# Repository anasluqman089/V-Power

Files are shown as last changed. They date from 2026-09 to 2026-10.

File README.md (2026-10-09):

# V-Power Handheld Console

V-Power handheld console

V-Power is a compact handheld console built around the Seeed Studio XIAO ESP32-S3 Sense. It brings together an OLED display, physical controls, a camera, SD-card storage, and battery monitoring in a custom PCB and 3D-printed case.

## Features

- Seeed Studio XIAO ESP32-S3 Sense
- 0.96-inch OLED display
- Four directional buttons and a rotary encoder
- Camera and photo gallery
- microSD card support
- MAX17043 battery fuel gauge
- Power indicator and low-battery LEDs
- Built-in Snake, Dodge, and Pong games in the `mini_handheld_console` project

## Bill of Materials

Prices are estimates and may change. The linked products are examples of the parts used for this build.

| Item | Component | Price (USD) | Qty | Example source |
| :--: | :--- | ---: | :--: | :--- |
| 1 | XIAO ESP32-S3 Sense | $13.90 | 1 | [Seeed Studio](https://www.seeedstudio.com/XIAO-ESP32S3-Sense-p-5639.html) |
| 2 | 0.96-inch OLED display | $6.99 | 1 | [Amazon](https://www.amazon.com/Dorhea-Display-3-3V-5V-Arduino-Raspberry/dp/B07FK8GB8T/ref=sr_1_5) |
| 3 | MAX17043 battery fuel gauge | $9.49 | 1 | [Amazon](https://www.amazon.com/HiLetgo-MAX17043-Lithium-Battery-Converter/dp/B01NBE99EP/ref=sr_1_3) |
| 4 | Rotary encoder | $6.99 | 1 | [Amazon](https://www.amazon.com/AIMPGSTL-Rotary-Encoder-Arduino-Raspberry/dp/B0FHDG9BKF/ref=sr_1_6) |
| 5 | Tactile push buttons | $4.99 | 4 | [Amazon](https://www.amazon.com/DAOKI-Miniature-Momentary-Tactile-Quality/dp/B01CGMP9GY/ref=sr_1_8) |
| 6 | LEDs | $6.99 | 2 | [Amazon](https://www.amazon.com/CHANZON-Assortment-Colors-Clear-Transparent/dp/B01AUI4VSI/ref=sr_1_6) |
| 7 | 40 x 30 x 8 mm Li-ion/LiPo battery | $2.20 | 1 | [Shopee](https://shopee.com.my/Original-Rechargeable-Battery-3.7V-150mAh-300mAh-600mAh-800mAh-1000mAh-1200mAh-1500mAh-3000mAh-5000mAh-bateri-china-cina-i.237274675.3651954444) |
| 8 | 3D printing | $5.00 | 1 | - |
| 9 | PCB | $4.00 | 1 | - |

## Controls

**Menu:** Turn the encoder to choose a game. Press **RIGHT** to launch it or **LEFT** to open the camera.

**Camera:** Press **RIGHT** to take a photo, **UP** to open the gallery, or **LEFT** to return to the menu.

**Gallery:** Turn the encoder to browse photos. Press **LEFT** to return to the camera.

**Games:** Use the directional buttons and encoder for game controls. Hold **LEFT** for five seconds to return to the menu.

The game-exit delay is set by `GAME_EXIT_TIME` in [the firmware pin definitions](Firmware/V-Power/mini_handheld_console/include/pins.h).

## Hardware Pinout

| Function | XIAO pin |
| :--- | :---: |
| UP button | D1 |
| Power LED | D2 |
| Low-battery LED | D3 |
| OLED and MAX17043 SDA | D4 |
| OLED and MAX17043 SCL | D5 |
| Rotary encoder A | D6 |
| Rotary encoder B | D7 |
| DOWN button | D8 |
| LEFT button | D9 |
| RIGHT button | D10 |

## Games and SD Card

The `mini_handheld_console` firmware includes Snake, Dodge, and Pong, which run without an SD card. The firmware also scans `/games` for files ending in `.GAM`, but external game files are not currently parsed or executed; selecting one displays a placeholder screen.

Photos taken with the camera are saved to `/photos`. The card is organized like this:

```text
games/
  game1.GAM
  game2.GAM
photos/
  PHOTO001.JPG
  PHOTO002.JPG
```

The gallery reads JPEG images from `/photos` and displays them on the OLED.

## Battery LEDs

The MAX17043 reports battery charge over I²C. The power LED stays on while the console is running. The warning LED blinks when the reported charge is at or below 15%; this threshold is defined by `LOW_BATTERY_PERCENT` in [the firmware pin definitions](Firmware/V-Power/mini_handheld_console/include/pins.h).

## Hardware Note

The current pinout assigns D8, D9, and D10 to buttons. On the XIAO ESP32-S3 Sense, these pins are also used by the onboard microSD interface. As a result, the buttons and onboard SD card cannot reliably operate together with this wiring. Change the wiring and pin assignments, or use a different SD connection, before relying on both at once.

## Build and Assembly

1. Assemble the circuit using the PCB or jumper wires. Follow the pinout above and check the SD-card pin conflict before soldering.
2. Install the [PlatformIO IDE extension for VS Code](https://docs.platformio.org/en/latest/integration/ide/vscode.html).
3. Open `Firmware/V-Power/mini_handheld_console` in VS Code and build the project with PlatformIO.
4. Connect the XIAO ESP32-S3 Sense and upload the firmware.
5. Print the case from the CAD files, or make a case of your own.

*Finished*

## Schematic



## PCB





## CAD





### Body 





### LID



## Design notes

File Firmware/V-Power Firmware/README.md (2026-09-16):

# Mini Handheld Console

## Project

PlatformIO project for XIAO ESP32-S3 Sense with 128x64 OLED, four buttons, rotary encoder, two LEDs, MAX17043, camera and onboard microSD.

## Controls

Menu: encoder moves, RIGHT launches, LEFT enters camera.
Camera: RIGHT takes photo, UP opens gallery, LEFT returns to menu.
Gallery: encoder browses, LEFT returns to camera.
Game: LEFT held for 5 seconds returns to menu.
LED1: on when powered.
LED2: blinks below the configured battery threshold.

## SD layout

/sd/games/*.GAM
/sd/photos/*.JPG

## Important hardware note

The XIAO ESP32-S3 Sense onboard microSD uses GPIO21 for CS and D8/D9/D10 for SPI. The requested SW2=D8, SW3=D9 and SW4=D10 therefore conflict with the onboard microSD interface. The firmware can compile with the requested pin map, but the SD card and those three buttons cannot reliably operate at the same time on the stock Sense SD connection. Move those button signals to unused GPIOs or use a different SD connection before expecting the SD features to work.

## Build

Open the folder in VS Code with PlatformIO and build/upload the project.

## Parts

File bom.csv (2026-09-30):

Item | Component | Price ($) | Qty | Buy Link
1 | XIAO ESP32-S3 Sense | $13.90 | 1 | https://www.seeedstudio.com/XIAO-ESP32S3-Sense-p-5639.html
2 | 0.96 Inch OLED Display | $6.99 | 1 | https://www.shopee.com.my/search?keyword=0.96%20OLED%20SSD1306%20128x64%20I2C
3 | MAX17043 | $9.49 | 1 | https://www.amazon.com/HiLetgo-MAX17043-Lithium-Battery-Converter/dp/B01NBE99EP/ref=sr_1_3
4 | Rotary Encoder | $6.99 | 1 | https://www.amazon.com/AIMPGSTL-Rotary-Encoder-Arduino-Raspberry/dp/B0FHDG9BKF/ref=sr_1_6
5 | Tactile Push Button | $4.99 | 4 | https://www.amazon.com/DAOKI-Miniature-Momentary-Tactile-Quality/dp/B01CGMP9GY/ref=sr_1_8
6 | LED | $6.99 | 2 | https://www.amazon.com/CHANZON-Assortment-Colors-Clear-Transparent/dp/B01AUI4VSI/ref=sr_1_6
7 | 40x30x8mm Li-ion/LiPo Battery | $2.20 | 1 | https://shopee.com.my/Original-Rechargeable-Battery-3.7V-150mAh-300mAh-600mAh-800mAh-1000mAh-1200mAh-1500mAh-3000mAh-5000mAh-bateri-china-cina-i.237274675.365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
8 | 3d printing | ~$5 | 1 | -
8 | PCB | $4.40 | 1 | -

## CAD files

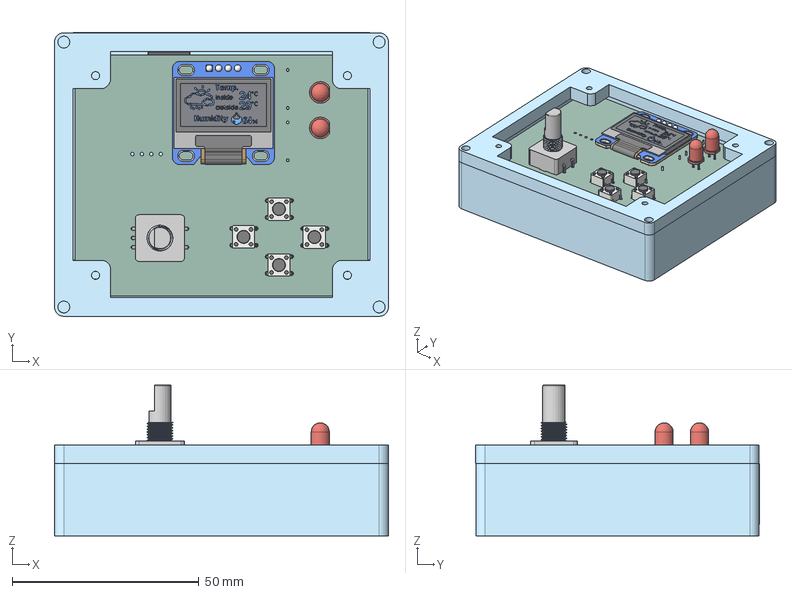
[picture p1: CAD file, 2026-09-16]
CAD/V-Power_CAD.step
89.5 x 76.0 x 40.4 mm
DF40HC(3.0)-30DS:1__Körper3
Seeed Studio XIAO-ESP32-S3 (Sense):1__PCB (1) x 16
LED_D5.0mm_1
V-Power_silkscreen x 6
DF40HC(3.0)-30DS:1__Körper14
JUSHUO AFC01-S24FCA-00:1__Körper23
Body:1__Körper1_1
JUSHUO AFC01-S24FCA-00:1__Körper19
SW_PUSH_6mm_2
BOSS-EXTRUDE14_7_:1__Körper1
BOSS-EXTRUDE7_8_:1__Körper1
DF40C-30DP-0.4V_51_ v1:1__Körper1
BOSS-EXTRUDE14_12_:1__Körper1
R_Axial_DIN0207_L63mm_D25mm_P1016mm_Horizontal
V-Power_PCB
JUSHUO AFC01-S24FCA-00:1__Körper11
DF40HC(3.0)-30DS:1__Körper1 (14)
BOSS-EXTRUDE14_4_:1__Körper1
DF40HC(3.0)-30DS:1__Körper1 (15)
Camer Module:1__Körper4
10067099-200LF v1:1__Körper1
BOSS-EXTRUDE14_9_:1__Körper1
JUSHUO AFC01-S24FCA-00:1__Körper3
LED_D5.0mm
JUSHUO AFC01-S24FCA-00:1__Körper6
JUSHUO AFC01-S24FCA-00:1__Körper7
Body:1__Körper1
DF40HC(3.0)-30DS:1__Körper10
DF40HC(3.0)-30DS:1__Körper1
DF40HC(3.0)-30DS:1__Körper1 (5)
DF40HC(3.0)-30DS:1__Körper4
DF40HC(3.0)-30DS:1__Körper1 (9)
DF40HC(3.0)-30DS:1__Körper9
MIRROR2:1__Körper1
JUSHUO AFC01-S24FCA-00:1__Körper12
BOSS-EXTRUDE14_5_:1__Körper1
Pins:1__Körper1
JUSHUO AFC01-S24FCA-00:1__Körper5
V-Power_soldermask x 2
Pins:1__Körper2
Camer Module:1__Körper3
BOSS-EXTRUDE14_1_:1__Körper1
Pins:1__Körper4
DF40HC(3.0)-30DS:1__Körper2
JUSHUO AFC01-S24FCA-00:1__Körper8
JUSHUO AFC01-S24FCA-00:1__Körper9
JUSHUO AFC01-S24FCA-00:1__Körper14
Camer Module:1__Körper2
JUSHUO AFC01-S24FCA-00:1__Körper20
JUSHUO AFC01-S24FCA-00:1__Körper17
Pins:1__Körper3
DF40HC(3.0)-30DS:1__Körper1 (7)
DF40HC(3.0)-30DS:1__Körper1 (8)
JUSHUO AFC01-S24FCA-00:1__Körper2
SW_PUSH_6mm_1
BOSS-EXTRUDE7_6_:1__Körper1
DF40HC(3.0)-30DS:1__Körper12
U.FL-R-SMT-1_10_ v1:1__Körper1
R_Axial_DIN0207_L63mm_D25mm_P1016mm_Horizontal_1
BOSS-EXTRUDE7_2_:1__Körper1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

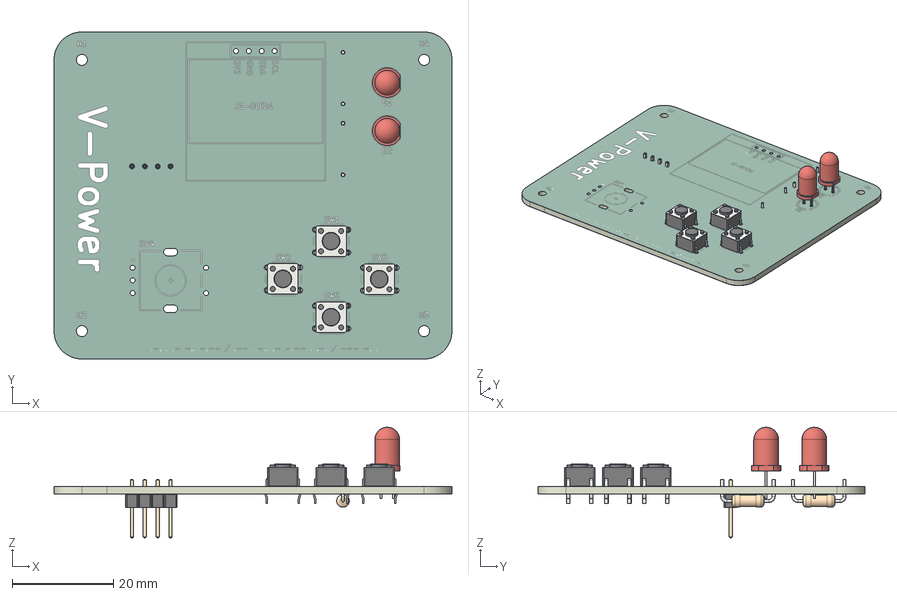
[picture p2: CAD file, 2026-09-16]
PCB/V-Power_PCB.step
78.5 x 64.5 x 21.8 mm
SW_PUSH_6mm x 4
LED_D5.0mm x 2
PinHeader_1x04_P254mm_Vertical
R_Axial_DIN0207_L63mm_D25mm_P1016mm_Horizontal x 2
V-Power_silkscreen x 2
V-Power_soldermask x 2
V-Power_PCB

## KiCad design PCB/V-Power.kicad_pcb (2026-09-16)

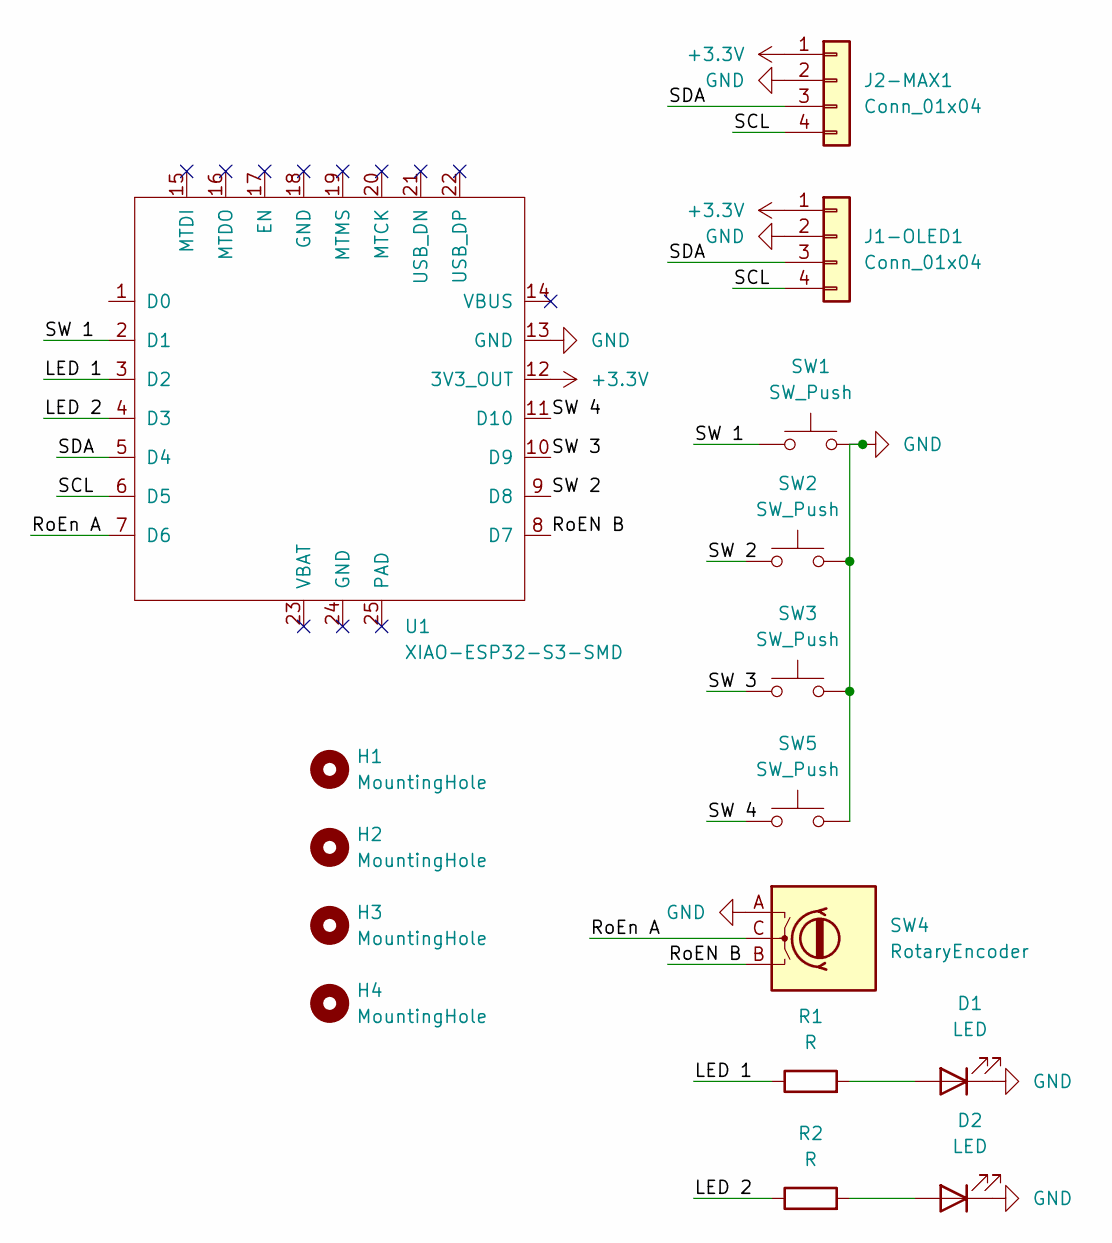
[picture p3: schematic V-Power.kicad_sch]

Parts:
D1, D2: LED; LED_D5.0mm
H1, H2, H3, H4: MountingHole; MountingHole_2.2mm_M2
J1-OLED1: Conn_01x04; 128x64OLED
J2-MAX1: Conn_01x04; PinHeader_1x04_P2.54mm_Vertical
R1, R2: R; R_Axial_DIN0207_L6.3mm_D2.5mm_P10.16mm_Horizontal
SW1, SW2, SW3, SW5: SW_Push; SW_PUSH_6mm
SW4: RotaryEncoder; RotaryEncoder_Alps_EC11E_Vertical_H20mm
U1: XIAO-ESP32-S3-SMD

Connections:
+3.3V: J1-OLED1.1, J2-MAX1.1, U1.12 (3V3_OUT)
/LED 1: R1.1, U1.3 (D2)
/LED 2: R2.1, U1.4 (D3)
/RoEN B: SW4.B, U1.8 (D7)
/RoEn A: SW4.C, U1.7 (D6)
/SCL: J1-OLED1.4, J2-MAX1.4, U1.6 (D5)
/SDA: J1-OLED1.3, J2-MAX1.3, U1.5 (D4)
/SW 1: SW1.1, U1.2 (D1)
/SW 2: SW2.1, U1.9 (D8)
/SW 3: SW3.1, U1.10 (D9)
/SW 4: SW5.1, U1.11 (D10)
GND: D1.1 (K), D2.1 (K), J1-OLED1.2, J2-MAX1.2, SW1.2, SW2.2, SW3.2, SW4.A, SW5.2, U1.13 (GND)
unnamed: D1.2 (A), R1.2
unnamed: D2.2 (A), R2.2

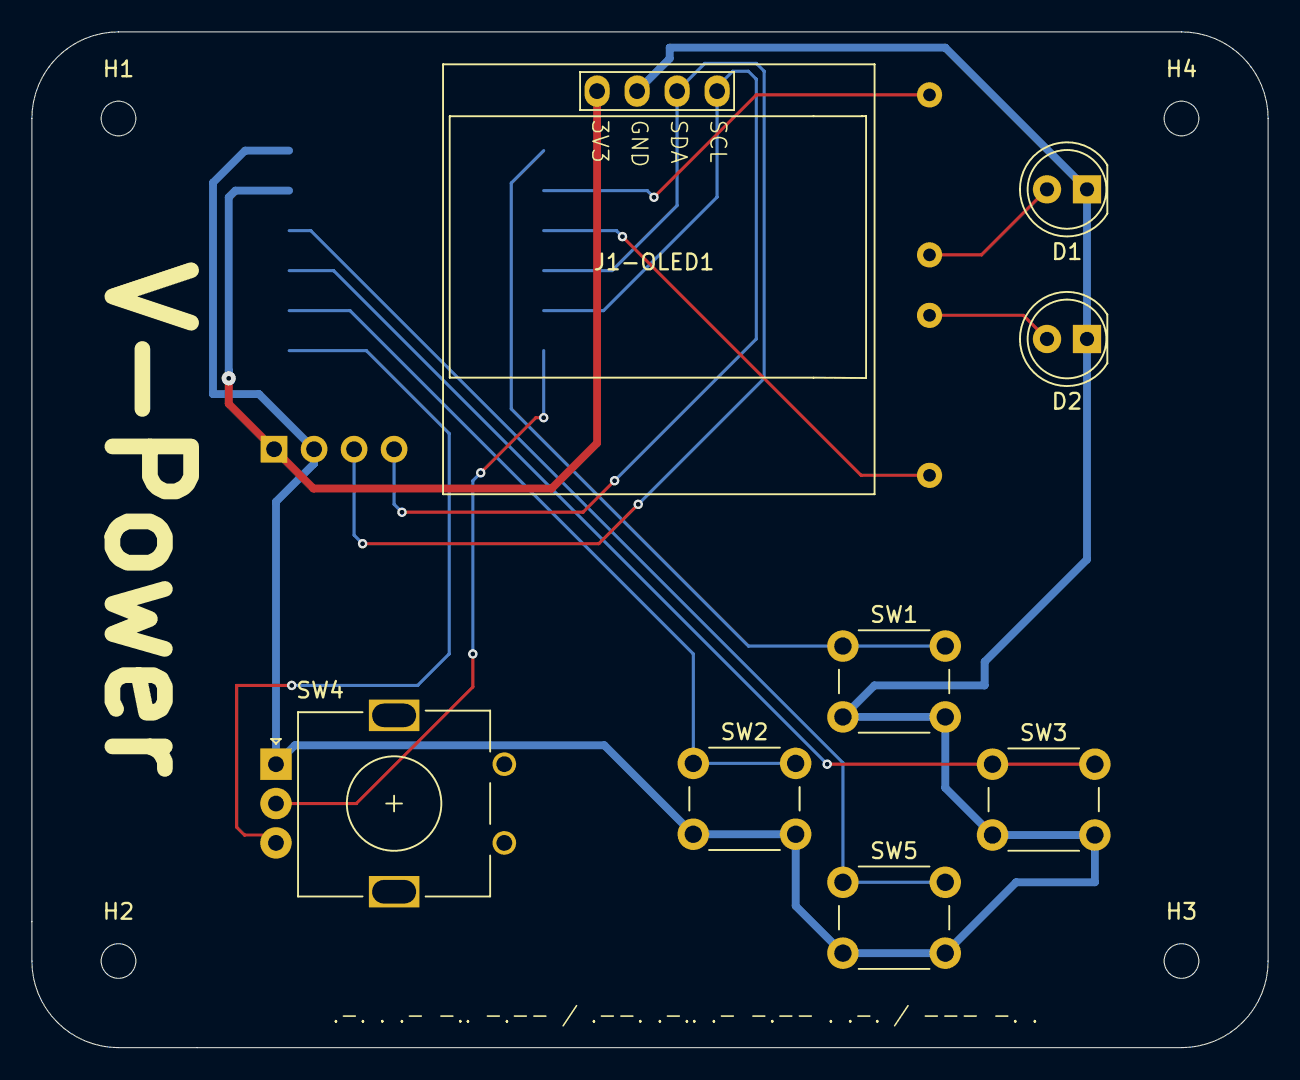
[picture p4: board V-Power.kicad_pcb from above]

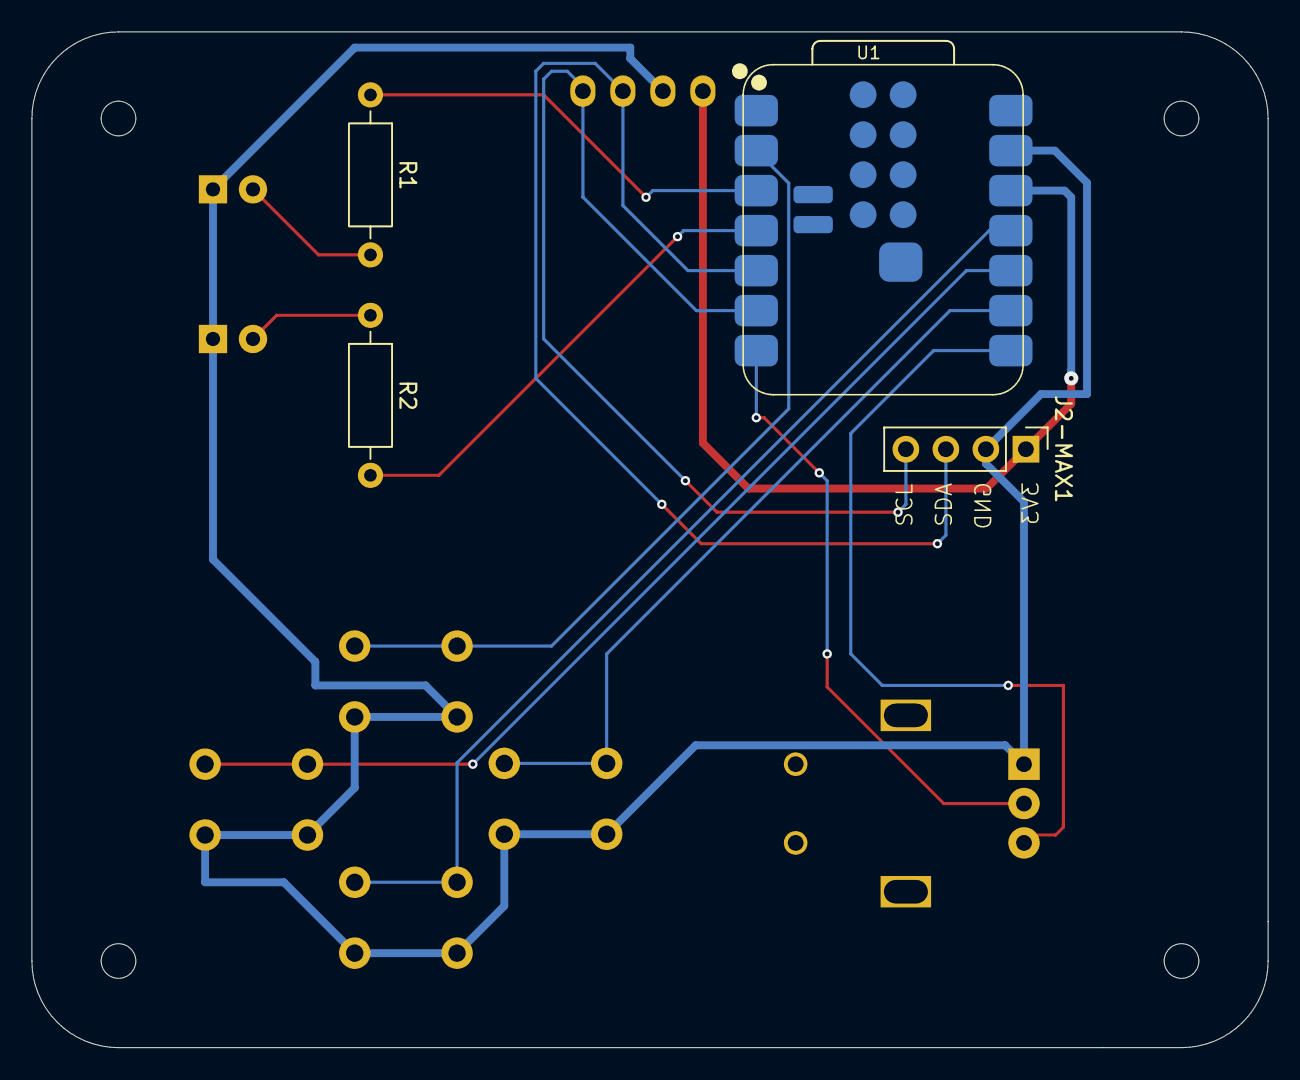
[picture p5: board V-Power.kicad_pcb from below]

Board: 2 copper layers, 78.5 x 64.5 mm, 16 parts (4 on the bottom side), 14 nets.

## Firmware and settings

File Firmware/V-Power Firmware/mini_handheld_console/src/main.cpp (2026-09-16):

#include <Arduino.h>
#include <Wire.h>
#include <SD.h>

#include "pins.h"
#include "display.h"
#include "input.h"
#include "battery.h"
#include "storage.h"
#include "camera.h"
#include "menu.h"
#include "gallery.h"
#include "game.h"

enum Mode {
    MODE_MENU,
    MODE_GAME,
    MODE_CAMERA,
    MODE_GALLERY
};

static Mode mode = MODE_MENU;
static int gameIndex = 0;
static int photoIndex = 0;
static unsigned long leftStart = 0;
static bool lowBatteryState = false;
static unsigned long lowBatteryBlink = 0;

static void cameraScreen() {
    display.clearDisplay();
    display.setCursor(0, 0);
    display.print("CAMERA");
    display.drawLine(0, 9, 127, 9, SSD1306_WHITE);
    display.setCursor(6, 20);
    display.print("RIGHT TAKE PHOTO");
    display.setCursor(6, 32);
    display.print("UP GALLERY");
    display.setCursor(6, 44);
    display.print("LEFT MENU");
    display.display();
}

static void handleBatteryLed() {
    batteryUpdate();
    if (batteryPercent() <= LOW_BATTERY_PERCENT) {
        if (millis() - lowBatteryBlink >= 400) {
            lowBatteryBlink = millis();
            lowBatteryState = !lowBatteryState;
            digitalWrite(LED2, lowBatteryState);
        }
    } else {
        lowBatteryState = false;
        digitalWrite(LED2, LOW);
    }
}

static void menuLoop() {
    int delta = encoderDelta();
    if (delta) {
        gameIndex += (delta > 0 ? 1 : -1);
        if (gameIndex < 0) gameIndex = 0;
        if (gameIndex >= (int)gameFiles.size()) gameIndex = gameFiles.empty() ? 0 : gameFiles.size() - 1;
    }

    if (buttonPressed(BUTTON_RIGHT) && !gameFiles.empty()) {
        gameBegin(gameFiles[gameIndex]);
        mode = MODE_GAME;
        leftStart = 0;
    }

    if (buttonPressed(BUTTON_LEFT)) {
        mode = MODE_CAMERA;
    }

    menuDraw(gameIndex);
}

static void cameraLoop() {
    if (buttonPressed(BUTTON_RIGHT)) {
        if (takePhoto()) {
            displayMessage("PHOTO SAVED");
            delay(400);
        } else {
            displayMessage("PHOTO ERROR");
            delay(400);
        }
    }

    if (buttonPressed(BUTTON_UP)) {
        scanPhotos();
        photoIndex = 0;
        mode = MODE_GALLERY;
        return;
    }

    if (buttonPressed(BUTTON_LEFT)) {
        mode = MODE_MENU;
        return;
    }

    cameraScreen();
}

static void galleryLoop() {
    int delta = encoderDelta();
    if (delta && !photoFiles.empty()) {
        photoIndex += (delta > 0 ? 1 : -1);
        if (photoIndex < 0) photoIndex = 0;
        if (photoIndex >= (int)photoFiles.size()) photoIndex = photoFiles.size() - 1;
    }

    if (buttonPressed(BUTTON_LEFT)) {
        mode = MODE_CAMERA;
        return;
    }

    galleryDraw(photoIndex);
}

static void gameLoop() {
    if (buttonDown(BUTTON_LEFT)) {
        if (leftStart == 0) leftStart = millis();
        if (millis() - leftStart >= GAME_EXIT_TIME) {
            leftStart = 0;
            mode = MODE_MENU;
            return;
        }
    } else {
        leftStart = 0;
    }

    gameUpdate();
}

void setup() {
    pinMode(LED1, OUTPUT);
    pinMode(LED2, OUTPUT);
    digitalWrite(LED1, HIGH);
    digitalWrite(LED2, LOW);

    inputBegin();
    Wire.begin(SDA_PIN, SCL_PIN);
    displayBegin();
    batteryBegin();

    displayMessage("STARTING...");

    if (storageBegin()) {
        displayMessage("SD OK");
    } else {
        displayMessage("NO SD");
    }

    cameraBegin();
    delay(500);
}

void loop() {
    inputUpdate();
    handleBatteryLed();

    switch (mode) {
        case MODE_MENU:
            menuLoop();
            break;
        case MODE_GAME:
            gameLoop();
            break;
        case MODE_CAMERA:
            cameraLoop();
            break;
        case MODE_GALLERY:
            galleryLoop();
            break;
    }

    delay(5);
}

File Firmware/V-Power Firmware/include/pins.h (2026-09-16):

#pragma once

#define SW1_UP D1
#define LED1 D2
#define LED2 D3
#define SDA_PIN D4
#define SCL_PIN D5
#define ENC_A D6
#define ENC_B D7
#define SW2_DOWN D8
#define SW3_LEFT D9
#define SW4_RIGHT D10
#define SD_CS 21

#define OLED_ADDR 0x3C
#define GAME_EXIT_TIME 5000UL
#define LOW_BATTERY_PERCENT 15.0f

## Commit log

2026-09-16 Enhance README with detailed V-Power information
    Expanded the description of V-Power and added detailed features, controls, hardware pinout, LED functions, game information, and SD card structure.
2026-09-16 Revise BOM with updated quantities and LED entries
    Updated quantities and combined LED entries in BOM.
    [bom.csv]
2026-09-20 Edit the directory and updated the name
    [V-Power.kicad_pcb, V-Power.kicad_sch, V-Power.step]
2026-09-22 Revise BOM format and add price information
    Updated BOM to include prices and revised format.
    [bom.csv]
2026-09-22 Fix BOM CSV formatting and update item list
    [bom.csv]
2026-09-22 Fix formatting issues in bom.csv
    [bom.csv]
2026-09-23 updated the readme.md
    [V-Power_CAD.step, V-Power_PCB.step]
2026-09-23 Add 3D printing item to BOM
    Added a new item for 3D printing to the BOM.
    [bom.csv]
2026-09-23 Fix formatting and item details in bom.csv
    Updated the BOM file to correct formatting and item details.
    [bom.csv]
2026-09-23 Fix OLED Display description in bom.csv
    Updated the description of the 0.96 OLED Display from '0.96"' to '0.96 Inch'.
    [bom.csv]
2026-09-23 Add BOM section with components and prices
    Added a Bill of Materials (BOM) section with item details, prices, and buy links.
2026-09-30 Add PCB item to bill of materials
    Added a new item 'PCB' with a price of $4.40 to the BOM.
    [bom.csv]
2026-09-30 change the directory
    [V-Power.kicad_pcb, V-Power.kicad_sch, V-Power_CAD.step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]
2026-10-09 Add mini handheld console firmware with game functionality
    - Implemented game system with three built-in games: Snake, Dodge, and Pong.
    - Created input handling for buttons and rotary encoder.
    - Developed display functions for game menus and game over screens.
    - Integrated SD card storage for game and photo management.
    - Added camera functionality for taking and storing photos.
    - Implemented battery monitoring and low battery indication.
    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
